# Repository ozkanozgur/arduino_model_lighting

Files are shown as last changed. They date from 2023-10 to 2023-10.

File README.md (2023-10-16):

# Model Lighting for Plastic or Diecast models.

You can make lighting for your plastic or diecast models.

Arduino project files, KiCad PCB design files are in this project.

If you don't want to use reed relays, you can replace reed relay with pullup buttons, or pullup short circuits. If you choose pullup buttons or pullup shortcircuits, you need use codes in "without-reed-relays" branch.

P.S.: Please, test circuit on breadboard before make/create final circuit.

### Complete component list is below.

- 1 x Arduino Uno
- 1 x Extra AT Mega 328 P Series Chip
- 12 x White LED (if neccessary for project you can use warm white led.)
- 4 x Red LED
- 4 x Yellow LED
- 10 x 470 ohm SMD Resistor (You can use 330 ohm.)
- 1 x Push Button
- 5 x Magnetic Reed Relay
- 5 x Neodium Magnet (I have used 3mm disc.)
- 2 x 22pF Capasitor
- 1 x 16.000 MHz Crystal
- 1 x 1838B IR Receiver
- 1 x 38KHz IR Remote Controller

### IR Remote Controller Button Functions

- OK => System on/off
- 1 => Parking lights on/off
- 2 => Dipped beam on/off
- 3 => High beam on/off
- 4 => Left turn signal on/off
- 5 => Right turn signal on/off
- 6 => Brake ligth on/off
- 7 => Hazard warning ligths on/off
- 8 => Reverse light on/off

# Plastik yada Diecast Modeller İçin Aydınlatma.

Bu projeyi kullanarak plastik yada diecast modellerinize uzaktan kumanda kontrollü ışıklandırma yapabilirsiniz.

Arduino proje dosyaları ve KiCad baskı devre tasarım dosyaları dahildir.

Eğer reed röleler yerine pullup button yada pullup kısa devre yapmak isterseniz, "without-reed-relays" branchi içerisindeki kodları kullanmanız gerekmektedir.

NOT: Lütfen devrenin baskı halini yapmadan önce breadboard üzerinde testlerinizi yapın.

### Komponent Listesi

- 1 x Arduino Uno
- 1 x Ekstra AT Mega 328 P Serisi Entegre Çip
- 12 x Beyaz LED (Projenize göre gün ışığı led de olabilir.)
- 4 x Kırmızı LED
- 4 x Sarı LED
- 10 x 470 ohm SMD Direnç (330 ohm da kullanılabilir.)
- 1 x Push Button
- 5 x Magnetic Reed Röle
- 5 x Neodium Mıknatıs (Ben 3mm yuvarlak olanlardan kullandım.)
- 2 x 22pF Kondansatör
- 1 x 16.000 MHz Kristal
- 1 x 1838B IR Alıcı
- 1 x 38KHz IR Uzaktan Kumanda

### IR Uzaktan Kumanda DÜğme Fonksiyonları

- OK => Sistem aç/kapat
- 1 => Parklar aç/kapat
- 2 => Kısalar aç/kapat
- 3 => Uzunlar aç/kapat
- 4 => Sol sinyal aç/kapat
- 5 => Sağ sinyal aç/kapat
- 6 => Fren lambası aç/kapat
- 7 => Dörtlüler aç/kapat
- 8 => Geri vites lambası aç/kapat
- Sol Ok => Sol sinyal aç/kapat
- Sağ Ok => Sağ sinyal aç/kapat

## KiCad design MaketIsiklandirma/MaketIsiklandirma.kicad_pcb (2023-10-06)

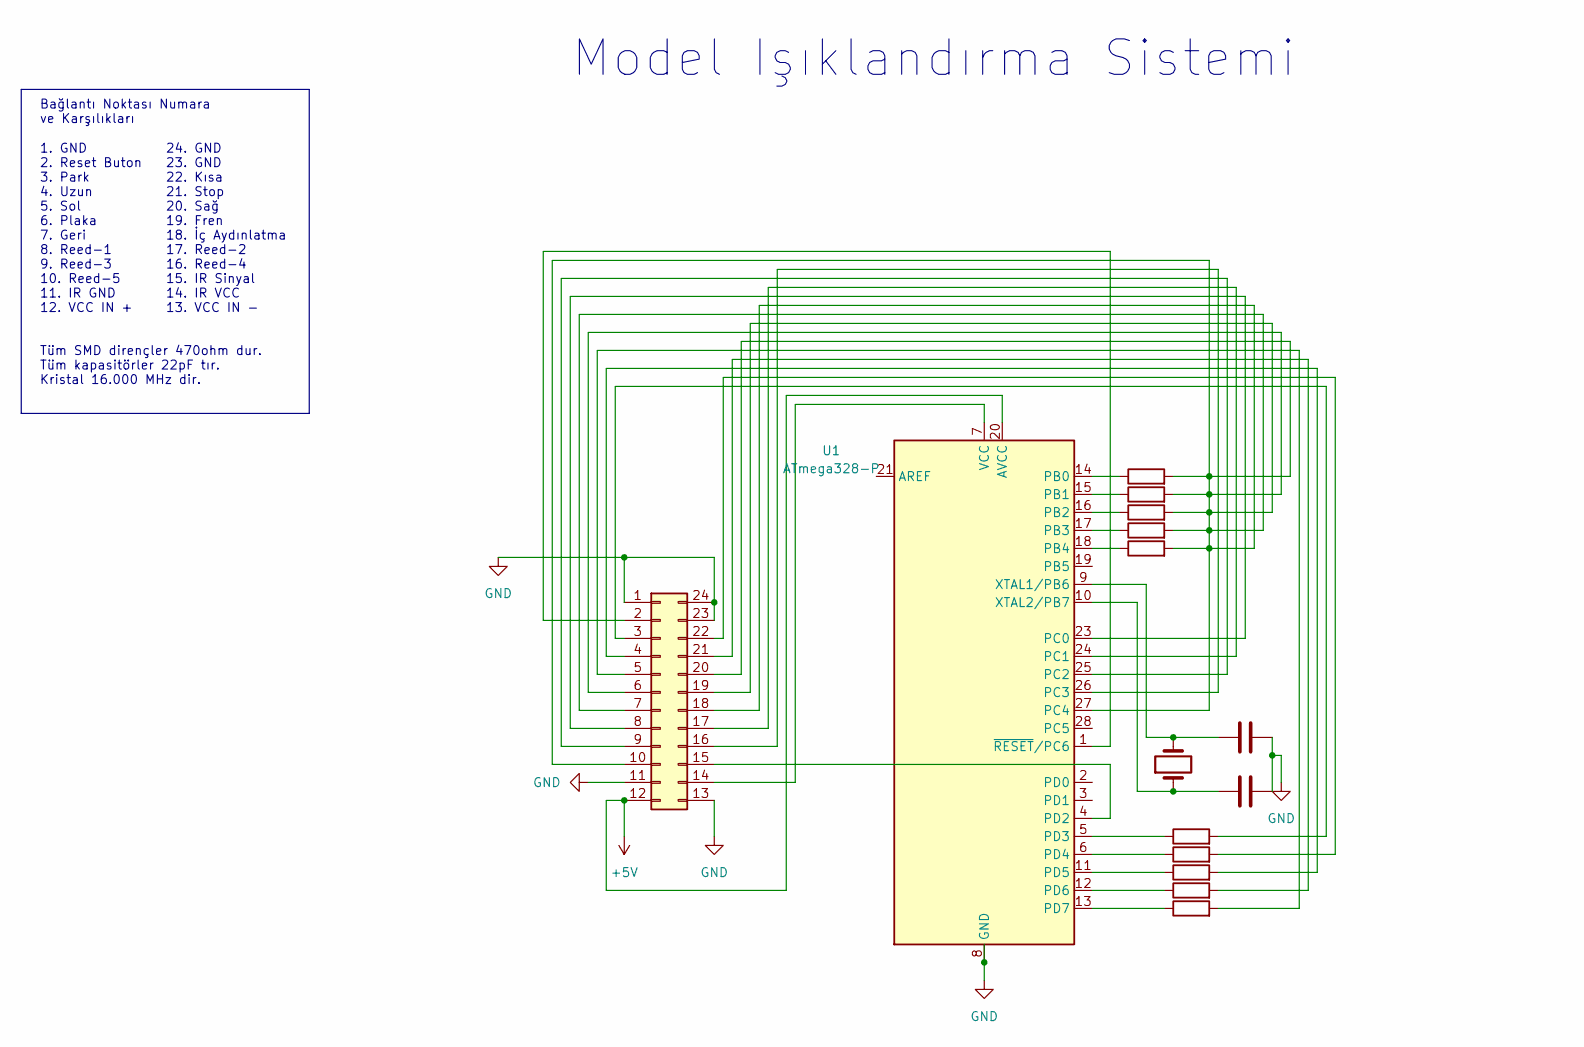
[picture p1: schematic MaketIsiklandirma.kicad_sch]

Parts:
C1, C2: C; C_Disc_D8.0mm_W5.0mm_P5.00mm
J3: Conn_02x12_Counter_Clockwise; IDC-Header_2x12_P2.54mm_Vertical
R1, R2, R3, R4, R5, R6, R7, R8, R9, R10: R; R_2512_6332Metric_Pad1.40x3.35mm_HandSolder
U1: ATmega328-P; DIP-28_W7.62mm
Y1: Crystal; Crystal_HC49-U_Vertical

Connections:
+5V: J3.12, U1.20 (AVCC)
unnamed: J3.3, R1.2
unnamed: J3.4, R3.2
unnamed: J3.5, R5.2
unnamed: J3.8, U1.23 (PC0)
unnamed: J3.9, U1.25 (PC2)
unnamed: J3.6, J3.7, J3.10, J3.18, J3.19, J3.20, R6.2, R7.2, R8.2, R9.2, R10.2, U1.27 (PC4)
unnamed: J3.14, U1.7 (VCC)
unnamed: J3.15, U1.4 (PD2)
unnamed: J3.16, U1.26 (PC3)
unnamed: J3.17, U1.24 (PC1)
unnamed: J3.21, R4.2
unnamed: J3.22, R2.2
unnamed: R10.1, U1.14 (PB0)
unnamed: R9.1, U1.15 (PB1)
unnamed: R8.1, U1.16 (PB2)
unnamed: R7.1, U1.17 (PB3)
unnamed: R6.1, U1.18 (PB4)
unnamed: R1.1, U1.5 (PD3)
unnamed: R2.1, U1.6 (PD4)
unnamed: R3.1, U1.11 (PD5)
unnamed: R4.1, U1.12 (PD6)
unnamed: R5.1, U1.13 (PD7)
unnamed: C2.1, U1.9 (XTAL1/PB6), Y1.2
unnamed: C1.1, U1.10 (XTAL2/PB7), Y1.1

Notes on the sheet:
Bağlantı Noktası Numara ve Karşılıkları
24. GND 23. GND 22. Kısa 21. Stop 20. Sağ 19. Fren 18. İç Aydınlatma 17. Reed-2 16. Reed-4 15. IR Sinyal 14. IR VCC 13. VCC IN -
Model Işıklandırma Sistemi
Tüm SMD dirençler 470ohm dur. Tüm kapasitörler 22pF tır. Kristal 16.000 MHz dir.
1. GND 2. Reset Buton 3. Park 4. Uzun 5. Sol 6. Plaka 7. Geri 8. Reed-1 9. Reed-3 10. Reed-5 11. IR GND 12. VCC IN +

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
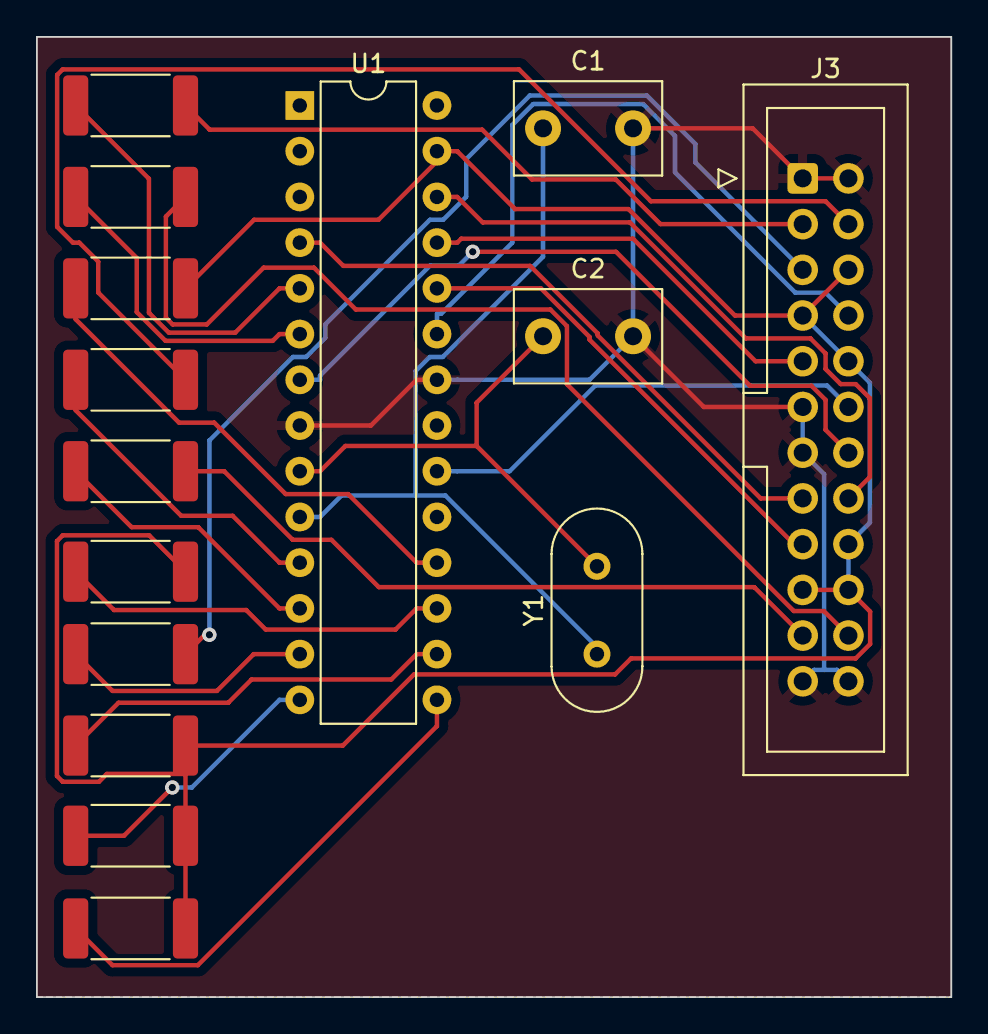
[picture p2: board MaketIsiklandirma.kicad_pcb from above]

Board: 2 copper layers, 50.8 x 53.3 mm, 15 parts (0 on the bottom side), 26 nets.

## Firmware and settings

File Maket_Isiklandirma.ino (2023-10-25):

/**
Uzaktan kumanda tuşları

1 -> Parklar Aç/Kapa (Kapatırken kısa ve uzun açıksa onlarda kapanır.)
2 -> Kısalar Aç/Kapa (Kapatırken uzunlar da açıksa uzunlar da kapanır.)
3 -> Uzunlar Aç/Kapa
4 -> Sol sinyaller Aç/Kapa (Açarken sağ sinyaller açıksa onlar kapanır.)
5 -> Sağ sinyaller Aç/Kapa (Açarken sol sinyaller açıksa onlar kapanır.)
6 -> Fren lambası Aç/Kapa
7 -> Dörtlüler Aç/Kapa
8 -> Geri vites lambası Aç/Kapa
OK -> Sistemi Aç/Kapa (Açınca kısa bir demo yapar.)
*/

#define DECODE_NEC
#include <Arduino.h>
#include "PinDefinitionsAndMore.h"
#include <IRremote.hpp>
#define LEDon  LOW
#define LEDoff !LEDon

#define PARK_LED 3
#define KISA_LED 4
#define UZUN_LED 5
#define STOP_LED 6
#define SOL_LED 7
#define SAG_LED 8
#define PLAKA_LED 9
#define FREN_LED 10
#define GERI_LED 11
#define IC_LED 12
#define reedPin1 A0
#define reedPin2 A1
#define reedPin3 A2
#define reedPin4 A3
#define reedPin5 A4

bool parkLedDurum = false;
bool kisaLedDurum = false;
bool uzunLedDurum = false;
bool stopLedDurum = false;
bool solLedDurum = false;
bool solLedState = LOW;
unsigned long solLedEskiZaman = 0;
bool sagLedState = LOW;
bool sagLedDurum = false;
unsigned long sagLedEskiZaman = 0;
bool plakaLedDurum = false;
bool frenLedDurum = false;
bool geriLedDurum = false;
bool icLedDurum = false;
bool dortluLedDurum = false;
bool dortluLedState = LOW;
unsigned long dortluLedEskiZaman = 0;

bool systemState = false;

void setup() {
  Serial.begin(115200);
  IrReceiver.begin(IR_RECEIVE_PIN, ENABLE_LED_FEEDBACK);

  pinMode(PARK_LED, OUTPUT);
  pinMode(KISA_LED, OUTPUT);
  pinMode(UZUN_LED, OUTPUT);
  pinMode(STOP_LED, OUTPUT);
  pinMode(SOL_LED, OUTPUT);
  pinMode(SAG_LED, OUTPUT);
  pinMode(PLAKA_LED, OUTPUT);
  pinMode(FREN_LED, OUTPUT);
  pinMode(GERI_LED, OUTPUT);
  pinMode(IC_LED, OUTPUT);
  pinMode(reedPin1, INPUT_PULLUP); 
  pinMode(reedPin2, INPUT_PULLUP); 
  pinMode(reedPin3, INPUT_PULLUP); 
  pinMode(reedPin4, INPUT_PULLUP); 
  pinMode(reedPin5, INPUT_PULLUP); 
}

unsigned long inMuteMs = 0;

void loop() {
  if(systemState == true){
    checkReeds();
  }

  if ( millis() - inMuteMs > 1000 && inMuteMs != 0 ) {
    // abandon old mute attempt
    inMuteMs = 0 ;
  }

  if(parkLedDurum == true && systemState == true){
    digitalWrite(STOP_LED, HIGH);
    digitalWrite(IC_LED, HIGH);
    digitalWrite(PLAKA_LED, HIGH);
  }else{
    digitalWrite(STOP_LED, LOW);
    digitalWrite(IC_LED, LOW);
    digitalWrite(PLAKA_LED, LOW);
  }

  if(solLedDurum == true && (millis() - solLedEskiZaman > 500) && systemState == true){
    solLedState = !solLedState;
    digitalWrite(SOL_LED, solLedState);
    solLedEskiZaman = millis();
  }

  if(sagLedDurum == true && (millis() - sagLedEskiZaman > 500) && systemState == true){
    sagLedState = !sagLedState;
    digitalWrite(SAG_LED, sagLedState);
    sagLedEskiZaman = millis();
  }

  if(dortluLedDurum == true && (millis() - dortluLedEskiZaman > 500) && systemState == true){
    dortluLedState = !dortluLedState;
    digitalWrite(SAG_LED, dortluLedState);
    digitalWrite(SOL_LED, dortluLedState);
    dortluLedEskiZaman = millis();
  }

  if (IrReceiver.decode()) {
    // Kısa farları aç/kapa
    if (IrReceiver.decodedIRData.command == 0x45 && (millis() - inMuteMs > 150) && systemState == true){
      // Serial.println("Button 1");
      parkLedDurum = !parkLedDurum;

      // Kısa ve Uzunları kapat
      if(parkLedDurum == false){
        kisaLedDurum = false;
        uzunLedDurum = false;
        digitalWrite(KISA_LED, LOW);
        digitalWrite(UZUN_LED, LOW);
      }

      digitalWrite(PARK_LED, parkLedDurum);
      inMuteMs = millis() ;
    } else if (IrReceiver.decodedIRData.command == 0x46 && (millis() - inMuteMs > 150) && systemState == true){
      // Serial.println("Button 2");
      kisaLedDurum = !kisaLedDurum;

      // Uzunları kapat
      if(kisaLedDurum == false){
        uzunLedDurum = false;
        digitalWrite(UZUN_LED, LOW);
      }else{
        parkLedDurum = true;
        digitalWrite(PARK_LED, HIGH);
      }

      digitalWrite(KISA_LED, kisaLedDurum);

      inMuteMs = millis() ;
    } else if (IrReceiver.decodedIRData.command == 0x47 && (millis() - inMuteMs > 150) && systemState == true){
      // Serial.println("Button 3");

      uzunLedDurum = !uzunLedDurum;

      if(uzunLedDurum == true){
        parkLedDurum = true;
        kisaLedDurum = true;
        digitalWrite(PARK_LED, HIGH);
        digitalWrite(KISA_LED, HIGH);
      }

      digitalWrite(UZUN_LED, uzunLedDurum);

      inMuteMs = millis() ;
    } else if (IrReceiver.decodedIRData.command == 0x44 && (millis() - inMuteMs > 150) && systemState == true){
      // Serial.println("Button 4");
      if(sagLedDurum == true){
        sagLedDurum = false;
        digitalWrite(SAG_LED, LOW);
        sagLedState = LOW;
        sagLedEskiZaman = 0;
      }

      if(dortluLedDurum == true){
        dortluLedDurum = false;
        digitalWrite(SAG_LED, LOW);
        digitalWrite(SOL_LED, LOW);
        dortluLedState = LOW;
        dortluLedEskiZaman = 0;
      }

      solLedDurum = !solLedDurum;
      inMuteMs = millis();
      if(solLedDurum == false){
        digitalWrite(SOL_LED, LOW);
        solLedState = LOW;
        solLedEskiZaman = 0;
      }
    } else if (IrReceiver.decodedIRData.command == 0x40 && (millis() - inMuteMs > 150) && systemState == true){
      // Serial.println("Button 5");
      if(solLedDurum == true){
        solLedDurum = false;
        digitalWrite(SOL_LED, LOW);
        solLedState = LOW;
        solLedEskiZaman = 0;
      }

      if(dortluLedDurum == true){
        dortluLedDurum = false;
        digitalWrite(SAG_LED, LOW);
        digitalWrite(SOL_LED, LOW);
        dortluLedState = LOW;
        dortluLedEskiZaman = 0;
      }

      sagLedDurum = !sagLedDurum;
      inMuteMs = millis();
      if(sagLedDurum == false){
        digitalWrite(SAG_LED, LOW);
        sagLedState = LOW;
        sagLedEskiZaman = 0;
      }
    } else if (IrReceiver.decodedIRData.command == 0x43 && (millis() - inMuteMs > 150) && systemState == true){
      // Serial.println("Button 6");
      frenLedDurum = !frenLedDurum;
      digitalWrite(FREN_LED, frenLedDurum);
      inMuteMs = millis() ;
    } else if (IrReceiver.decodedIRData.command == 0x7 && (millis() - inMuteMs > 150) && systemState == true){
      // Serial.println("Button 7");
      if(solLedDurum == true){
        solLedDurum = false;
        solLedState = LOW;
        solLedEskiZaman = 0;
        digitalWrite(SOL_LED, LOW);
      }

      if(sagLedDurum == true){
        sagLedDurum = false;
        sagLedState = LOW;
        sagLedEskiZaman = 0;
        digitalWrite(SAG_LED, LOW);
      }

      dortluLedDurum = !dortluLedDurum;            
      inMuteMs = millis();

      if(dortluLedDurum == false){
        sagLedState = LOW;
        sagLedEskiZaman = 0;
        solLedState = LOW;
        solLedEskiZaman = 0;
        digitalWrite(SAG_LED, LOW);
        digitalWrite(SOL_LED, LOW);
      }
    } else if (IrReceiver.decodedIRData.command == 0x15 && (millis() - inMuteMs > 150) && systemState == true){
      // Serial.println("Button 8");
      geriLedDurum = !geriLedDurum;
      digitalWrite(GERI_LED, geriLedDurum);
      inMuteMs = millis() ;
    } else if (IrReceiver.decodedIRData.command == 0x9){
      // Serial.println("Button 9");
    } else if (IrReceiver.decodedIRData.command == 0x19){
      // Serial.println("Button 0");
    } else if (IrReceiver.decodedIRData.command == 0x16){
      // Serial.println("Button *");
    } else if (IrReceiver.decodedIRData.command == 0xD){
      // Serial.println("Button #");
    } else if (IrReceiver.decodedIRData.command == 0x18){
      // Serial.println("Button Up");
    } else if (IrReceiver.decodedIRData.command == 0x8 && (millis() - inMuteMs > 150) && systemState == true){
      // Serial.println("Button Left");
      if(sagLedDurum == true){
        sagLedDurum = false;
        digitalWrite(SAG_LED, LOW);
        sagLedState = LOW;
        sagLedEskiZaman = 0;
      }

      if(dortluLedDurum == true){
        dortluLedDurum = false;
        digitalWrite(SAG_LED, LOW);
        digitalWrite(SOL_LED, LOW);
        dortluLedState = LOW;
        dortluLedEskiZaman = 0;
      }

      solLedDurum = !solLedDurum;
      inMuteMs = millis();
      if(solLedDurum == false){
        digitalWrite(SOL_LED, LOW);
        solLedState = LOW;
        solLedEskiZaman = 0;
      }
    } else if (IrReceiver.decodedIRData.command == 0x5A && (millis() - inMuteMs > 150) && systemState == true){
      // Serial.println("Button Right");
      if(solLedDurum == true){
        solLedDurum = false;
        digitalWrite(SOL_LED, LOW);
        solLedState = LOW;
        solLedEskiZaman = 0;
      }

      if(dortluLedDurum == true){
        dortluLedDurum = false;
        digitalWrite(SAG_LED, LOW);
        digitalWrite(SOL_LED, LOW);
        dortluLedState = LOW;
        dortluLedEskiZaman = 0;
      }

      sagLedDurum = !sagLedDurum;
      inMuteMs = millis();
      if(sagLedDurum == false){
        digitalWrite(SAG_LED, LOW);
        sagLedState = LOW;
        sagLedEskiZaman = 0;
      }
    } else if (IrReceiver.decodedIRData.command == 0x1C && (millis() - inMuteMs > 150)){
      demo();
      inMuteMs = millis();
    } else if (IrReceiver.decodedIRData.command == 0x52){
      // Serial.println("Button Down");
      inMuteMs = millis();
    }

    IrReceiver.resume(); 
  }
}

void demo(){
  if(systemState == false){
    digitalWrite(PARK_LED, HIGH);
    digitalWrite(STOP_LED, HIGH);
    digitalWrite(PLAKA_LED, HIGH);
    digitalWrite(IC_LED, HIGH);
    digitalWrite(KISA_LED, HIGH);
    delay(50);
    digitalWrite(PARK_LED, LOW);
    digitalWrite(STOP_LED, LOW);
    digitalWrite(PLAKA_LED, LOW);
    digitalWrite(IC_LED, LOW);
    digitalWrite(KISA_LED, LOW);
    delay(50);
    digitalWrite(PARK_LED, HIGH);
    digitalWrite(STOP_LED, HIGH);
    digitalWrite(PLAKA_LED, HIGH);
    digitalWrite(IC_LED, HIGH);
    digitalWrite(KISA_LED, HIGH);
    delay(50);
    digitalWrite(PARK_LED, LOW);
    digitalWrite(STOP_LED, LOW);
    digitalWrite(PLAKA_LED, LOW);
    digitalWrite(IC_LED, LOW);
    digitalWrite(KISA_LED, LOW);
    delay(50);
    digitalWrite(PARK_LED, HIGH);
    digitalWrite(STOP_LED, HIGH);
    digitalWrite(PLAKA_LED, HIGH);
    digitalWrite(IC_LED, HIGH);
    digitalWrite(KISA_LED, HIGH);
    delay(50);
    digitalWrite(PARK_LED, LOW);
    digitalWrite(STOP_LED, LOW);
    digitalWrite(PLAKA_LED, LOW);
    digitalWrite(IC_LED, LOW);
    digitalWrite(KISA_LED, LOW);
    delay(50);
    digitalWrite(PARK_LED, HIGH);
    digitalWrite(STOP_LED, HIGH);
    digitalWrite(PLAKA_LED, HIGH);
    digitalWrite(IC_LED, HIGH);
    digitalWrite(KISA_LED, HIGH);
    delay(50);
    digitalWrite(PARK_LED, LOW);
    digitalWrite(STOP_LED, LOW);
    digitalWrite(PLAKA_LED, LOW);
    digitalWrite(IC_LED, LOW);
    digitalWrite(KISA_LED, LOW);
    delay(50);

    digitalWrite(SOL_LED, HIGH);
    delay(50);
    digitalWrite(SOL_LED, LOW);
    delay(50);
    digitalWrite(SOL_LED, HIGH);
    delay(50);
    digitalWrite(SOL_LED, LOW);
    delay(50);
    digitalWrite(SOL_LED, HIGH);
    delay(50);
    digitalWrite(SOL_LED, LOW);
    delay(50);
    digitalWrite(SOL_LED, HIGH);
    delay(50);
    digitalWrite(SOL_LED, LOW);
    delay(50);

    digitalWrite(SAG_LED, HIGH);
    delay(50);
    digitalWrite(SAG_LED, LOW);
    delay(50);
    digitalWrite(SAG_LED, HIGH);
    delay(50);
    digitalWrite(SAG_LED, LOW);
    delay(50);
    digitalWrite(SAG_LED, HIGH);
    delay(50);
    digitalWrite(SAG_LED, LOW);
    delay(50);
    digitalWrite(SAG_LED, HIGH);
    delay(50);
    digitalWrite(SAG_LED, LOW);
    delay(50);

    digitalWrite(SOL_LED, HIGH);
    delay(50);
    digitalWrite(SOL_LED, LOW);
    delay(50);
    digitalWrite(SOL_LED, HIGH);
    delay(50);
    digitalWrite(SOL_LED, LOW);
    delay(50);
    digitalWrite(SOL_LED, HIGH);
    delay(50);
    digitalWrite(SOL_LED, LOW);
    delay(50);
    digitalWrite(SOL_LED, HIGH);
    delay(50);
    digitalWrite(SOL_LED, LOW);
    delay(50);

    digitalWrite(SAG_LED, HIGH);
    delay(50);
    digitalWrite(SAG_LED, LOW);
    delay(50);
    digitalWrite(SAG_LED, HIGH);
    delay(50);
    digitalWrite(SAG_LED, LOW);
    delay(50);
    digitalWrite(SAG_LED, HIGH);
    delay(50);
    digitalWrite(SAG_LED, LOW);
    delay(50);
    digitalWrite(SAG_LED, HIGH);
    delay(50);
    digitalWrite(SAG_LED, LOW);
    delay(50);

    systemState = true;
  }else{
    parkLedDurum = false;
    kisaLedDurum = false;
    uzunLedDurum = false;
    stopLedDurum = false;
    solLedDurum = false;
    solLedState = LOW;
    solLedEskiZaman = 0;
    sagLedState = LOW;
    sagLedDurum = false;
    sagLedEskiZaman = 0;
    plakaLedDurum = false;
    frenLedDurum = false;
    geriLedDurum = false;
    icLedDurum = false;
    dortluLedDurum = false;
    dortluLedState = LOW;
    dortluLedEskiZaman = 0;
    digitalWrite(PARK_LED, LOW);
    digitalWrite(KISA_LED, LOW);
    digitalWrite(UZUN_LED, LOW);
    digitalWrite(STOP_LED, LOW);
    digitalWrite(SOL_LED, LOW);
    digitalWrite(SAG_LED, LOW);
    digitalWrite(PLAKA_LED, LOW);
    digitalWrite(FREN_LED, LOW);
    digitalWrite(GERI_LED, LOW);
    digitalWrite(IC_LED, LOW);

    digitalWrite(KISA_LED, HIGH);
    digitalWrite(UZUN_LED, HIGH);
    digitalWrite(STOP_LED, HIGH);
    delay(500);
    digitalWrite(KISA_LED, LOW);
    digitalWrite(UZUN_LED, LOW);
    digitalWrite(STOP_LED, LOW);

    systemState = false;
  }
}

void checkReeds(){
  if(digitalRead(reedPin1) == HIGH || digitalRead(reedPin2) == HIGH || digitalRead(reedPin3) == HIGH || digitalRead(reedPin4) == HIGH || digitalRead(reedPin5) == HIGH){
    if(parkLedDurum == false){
      digitalWrite(IC_LED, HIGH);
    }
  }else{
    if(parkLedDurum == false){
      digitalWrite(IC_LED, LOW);
    }
  }
}

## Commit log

2023-10-06 Little bug fixes, added README file, and addes KiCad files
    [MaketIsiklandirma.kicad_pcb, MaketIsiklandirma.kicad_sch]
2023-10-13 Added functionality to remote controller left and right buttons. They open or close the turn indicators..
2023-10-13 Configured reed relays and reed relays light out pin
2023-10-25 Bug fix about short circuits and left and right buttons delay.
    [Maket_Isiklandirma.ino]
